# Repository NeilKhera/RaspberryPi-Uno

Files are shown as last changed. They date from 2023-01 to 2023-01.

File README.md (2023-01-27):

## RaspberryPi-Uno
<br/>

### Description
A pin-compatible Arduino Uno clone board for the Raspberry Pi RP2040 microcontroller.

Check out the resources folder for Circuitpython config files, or the Releases section for the compiled firmware .uf2!

### License

Designed by Neil Khera.

Creative Commons Attribution/Share-Alike, all text above must be included in any redistribution. See license.txt for additional details.

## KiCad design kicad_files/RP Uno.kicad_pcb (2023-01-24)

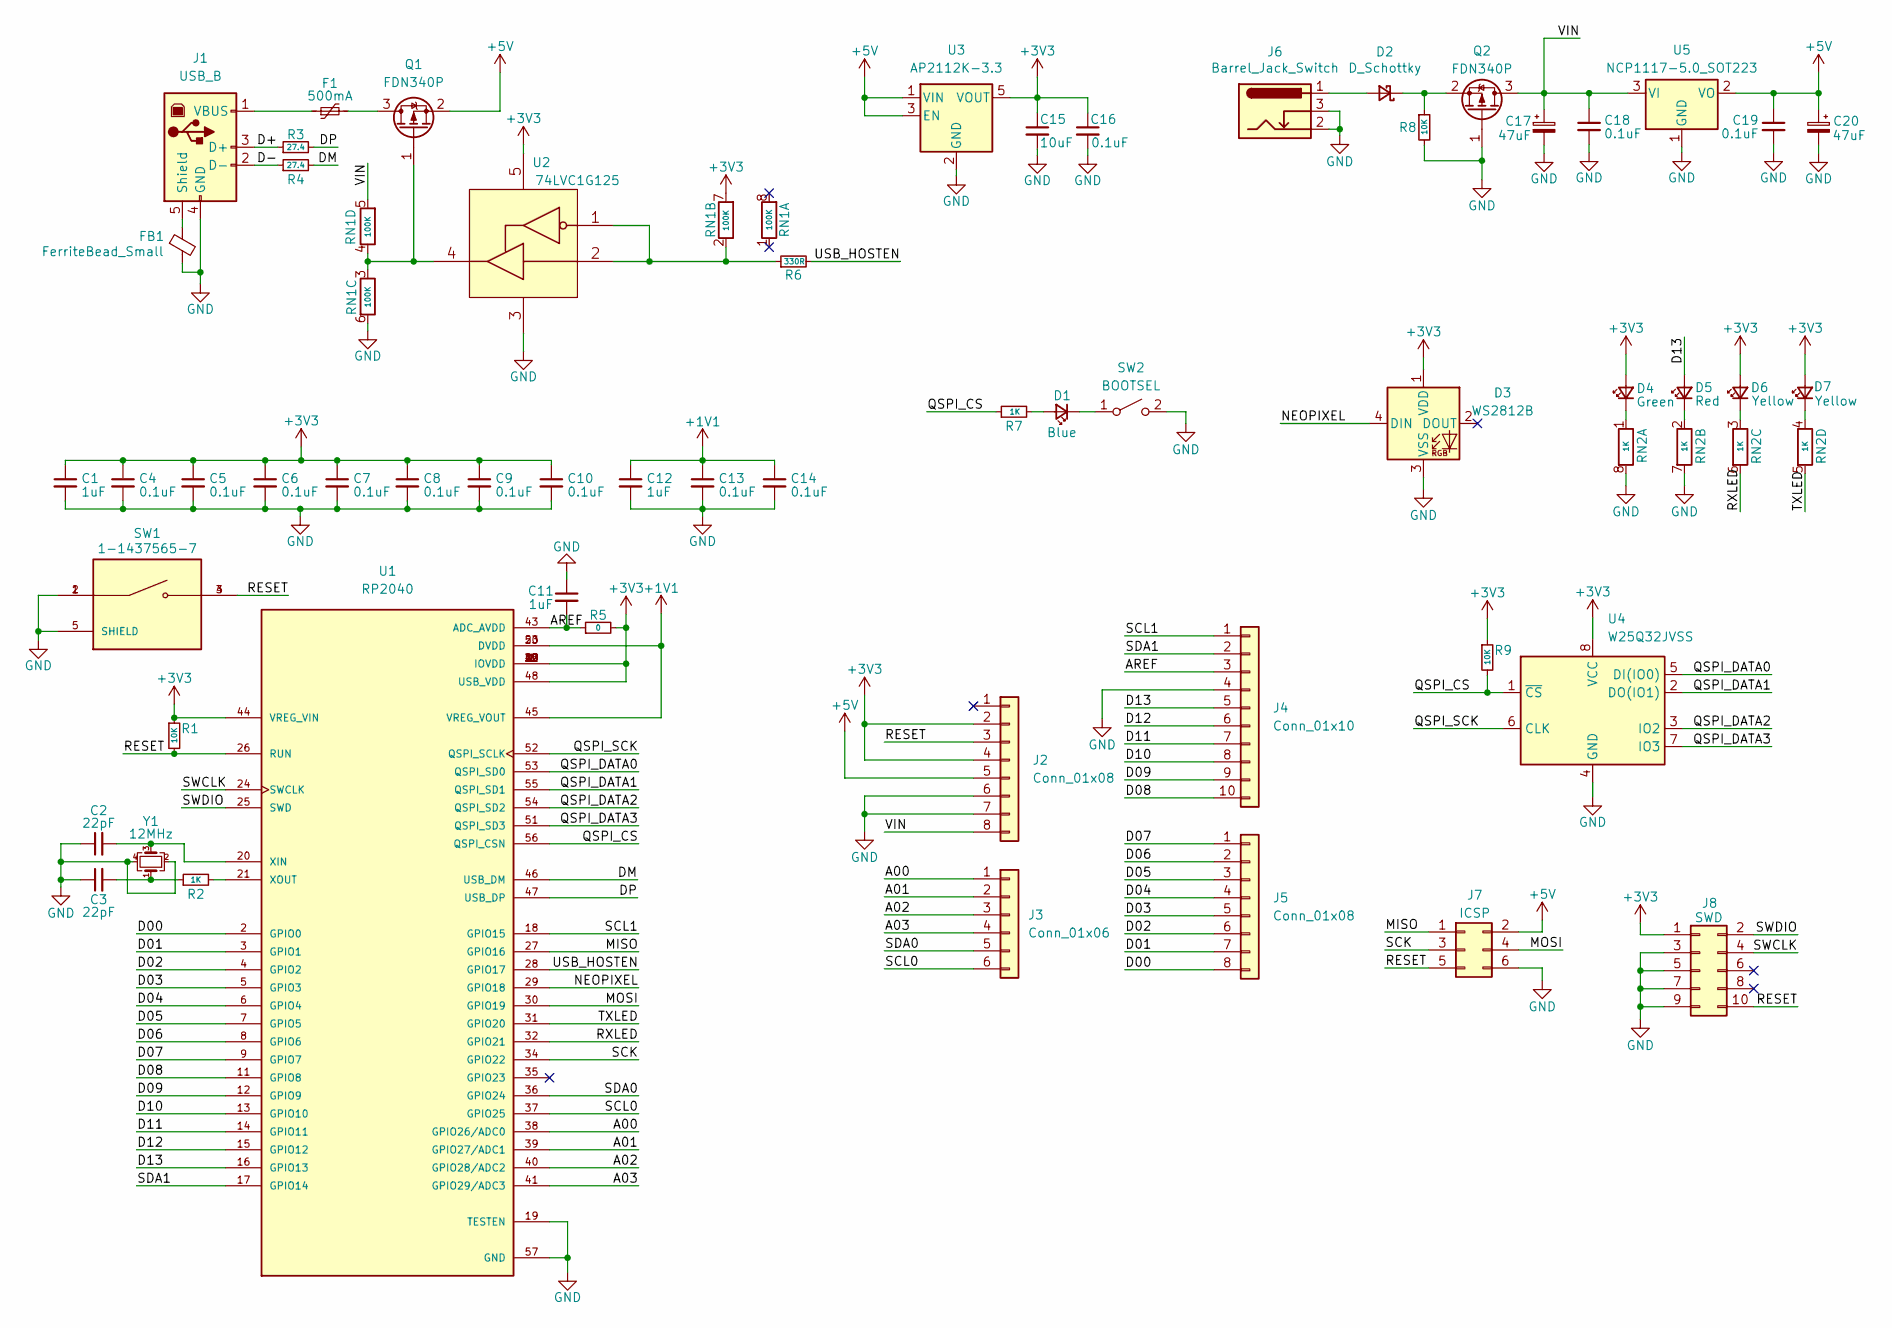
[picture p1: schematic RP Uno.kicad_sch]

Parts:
C1, C11, C12: 1uF; C_0603_1608Metric
C2, C3: 22pF; C_0603_1608Metric
C4, C5, C6, C7, C8, C9, C10, C13, C14, C16, C18, C19: 0.1uF; C_0603_1608Metric
C15: 10uF; C_0603_1608Metric
C17, C20: 47uF; CAPAE680X600N
D1: Blue; LED_0603_1608Metric
D2: D_Schottky; D_SMB
D3: WS2812B; LED_WS2812B_PLCC4_5.0x5.0mm_P3.2mm
D4: Green; LED_0603_1608Metric
D5: Red; LED_0603_1608Metric
D6, D7: Yellow; LED_0603_1608Metric
F1: 500mA; Fuse_1206_3216Metric
FB1: FerriteBead_Small; L_0603_1608Metric
J1: USB_B; USB_B_OST_USB-B1HSxx_Horizontal
J2, J5: Conn_01x08; PinSocket_1x08_P2.54mm_Vertical
J3: Conn_01x06; PinSocket_1x06_P2.54mm_Vertical
J4: Conn_01x10; PinSocket_1x10_P2.54mm_Vertical
J6: Barrel_Jack_Switch; BarrelJack_Horizontal
J7: ICSP; PinHeader_2x03_P2.54mm_Vertical
J8: SWD; 2X05_1.27MM_BOX_POSTS
Q1, Q2: FDN340P; SOT-23
R1, R8, R9: 10K; R_0603_1608Metric
R2, R7: 1K; R_0603_1608Metric
R3, R4: 27.4; R_0603_1608Metric
R5: 0; R_0603_1608Metric
R6: 330R; R_0603_1608Metric
RN1: 100K; R_Array_Concave_4x0603
RN2: 1K; R_Array_Concave_4x0603
SW1: 1-1437565-7; SW_1-1437565-7
SW2: BOOTSEL; SW_SPST_B3U-1000P
U1: RP2040; QFN40P700X700X90-57N; PARTREV 1.6.1
U2: 74LVC1G125; SOT-23-5
U3: AP2112K-3.3; SOT-23-5
U4: W25Q32JVSS; SOIC-8_5.23x5.23mm_P1.27mm
U5: NCP1117-5.0_SOT223; SOT-223-3_TabPin2
Y1: 12MHz; Crystal_SMD_2520-4Pin_2.5x2.0mm

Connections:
+1V1: C12.1, C13.1, C14.1, U1.23 (DVDD), U1.45 (VREG_VOUT), U1.50 (DVDD)
+3V3: C1.1, C4.1, C5.1, C6.1, C7.1, C8.1, C9.1, C10.1, C15.1, C16.1, D3.1 (VDD), D4.2 (A), D6.2 (A), D7.2 (A), J2.2, J2.4, J8.1, R1.1, R5.2, R9.1, RN1.7 (R2.2), U1.1 (IOVDD), U1.10 (IOVDD), U1.22 (IOVDD), U1.33 (IOVDD), U1.42 (IOVDD), U1.44 (VREG_VIN), U1.48 (USB_VDD), U1.49 (IOVDD), U2.5 (VCC), U3.5 (VOUT), U4.8 (VCC)
+5V: C19.1, C20.1, J2.5, J7.2, Q1.2 (S), U3.1 (VIN), U3.3 (EN), U5.2 (VO)
/A00: J3.1, U1.38 (GPIO26/ADC0)
/A01: J3.2, U1.39 (GPIO27/ADC1)
/A02: J3.3, U1.40 (GPIO28/ADC2)
/A03: J3.4, U1.41 (GPIO29/ADC3)
/AREF: C11.2, J4.3, R5.1, U1.43 (ADC_AVDD)
/D00: J5.8, U1.2 (GPIO0)
/D01: J5.7, U1.3 (GPIO1)
/D02: J5.6, U1.4 (GPIO2)
/D03: J5.5, U1.5 (GPIO3)
/D04: J5.4, U1.6 (GPIO4)
/D05: J5.3, U1.7 (GPIO5)
/D06: J5.2, U1.8 (GPIO6)
/D07: J5.1, U1.9 (GPIO7)
/D08: J4.10, U1.11 (GPIO8)
/D09: J4.9, U1.12 (GPIO9)
/D10: J4.8, U1.13 (GPIO10)
/D11: J4.7, U1.14 (GPIO11)
/D12: J4.6, U1.15 (GPIO12)
/D13: D5.2 (A), J4.5, U1.16 (GPIO13)
/D+: J1.3 (D+), R3.1
/D-: J1.2 (D-), R4.1
/DM: R4.2, U1.46 (USB_DM)
/DP: R3.2, U1.47 (USB_DP)
/MISO: J7.1, U1.27 (GPIO16)
/MOSI: J7.4, U1.30 (GPIO19)
/NEOPIXEL: D3.4 (DIN), U1.29 (GPIO18)
/QSPI_CS: R7.1, R9.2, U1.56 (QSPI_CSN), U4.1 (~CS)
/QSPI_DATA0: U1.53 (QSPI_SD0), U4.5 (DI(IO0))
/QSPI_DATA1: U1.55 (QSPI_SD1), U4.2 (DO(IO1))
/QSPI_DATA2: U1.54 (QSPI_SD2), U4.3 (IO2)
/QSPI_DATA3: U1.51 (QSPI_SD3), U4.7 (IO3)
/QSPI_SCK: U1.52 (QSPI_SCLK), U4.6 (CLK)
/RESET: J2.3, J7.5, J8.10, R1.2, SW1.3, SW1.4, U1.26 (RUN)
/RXLED: RN2.6 (R3.2), U1.32 (GPIO21)
/SCK: J7.3, U1.34 (GPIO22)
/SCL0: J3.6, U1.37 (GPIO25)
/SCL1: J4.1, U1.18 (GPIO15)
/SDA0: J3.5, U1.36 (GPIO24)
/SDA1: J4.2, U1.17 (GPIO14)
/SWCLK: J8.4, U1.24 (SWCLK)
/SWDIO: J8.2, U1.25 (SWD)
/TXLED: RN2.5 (R4.2), U1.31 (GPIO20)
/USB_HOSTEN: R6.2, U1.28 (GPIO17)
/VIN: C17.1, C18.1, J2.8, Q2.3 (D), RN1.5 (R4.2), U5.3 (VI)
GND: C1.2, C2.1, C3.1, C4.2, C5.2, C6.2, C7.2, C8.2, C9.2, C10.2, C11.1, C12.2, C13.2, C14.2, C15.2, C16.2, C17.2, C18.2, C19.2, C20.2, D3.3 (VSS), FB1.2, J1.4 (GND), J2.6, J2.7, J4.4, J6.2, J6.3, J7.6, J8.3, J8.5, J8.7, J8.9, Q2.1 (G), R8.2, RN1.6 (R3.2), RN2.7 (R2.2), RN2.8 (R1.2), SW1.1, SW1.2, SW1.5 (SHIELD), SW2.2 (B), U1.19 (TESTEN), U1.57 (GND), U2.3 (GND), U3.2 (GND), U4.4 (GND), U5.1 (GND), Y1.2, Y1.4
unnamed: C2.2, U1.20 (XIN), Y1.3
unnamed: C3.2, R2.1, Y1.1
unnamed: D1.1 (K), SW2.1 (A)
unnamed: D1.2 (A), R7.2
unnamed: D2.1 (K), Q2.2 (S), R8.1
unnamed: D2.2 (A), J6.1
unnamed: D4.1 (K), RN2.1 (R1.1)
unnamed: D5.1 (K), RN2.2 (R2.1)
unnamed: D6.1 (K), RN2.3 (R3.1)
unnamed: D7.1 (K), RN2.4 (R4.1)
unnamed: F1.1, J1.1 (VBUS)
unnamed: F1.2, Q1.3 (D)
unnamed: FB1.1, J1.5 (Shield)
unnamed: Q1.1 (G), RN1.3 (R3.1), RN1.4 (R4.1), U2.4 (Y)
unnamed: R2.2, U1.21 (XOUT)
unnamed: R6.1, RN1.2 (R2.1), U2.1 (OE_N), U2.2 (A)

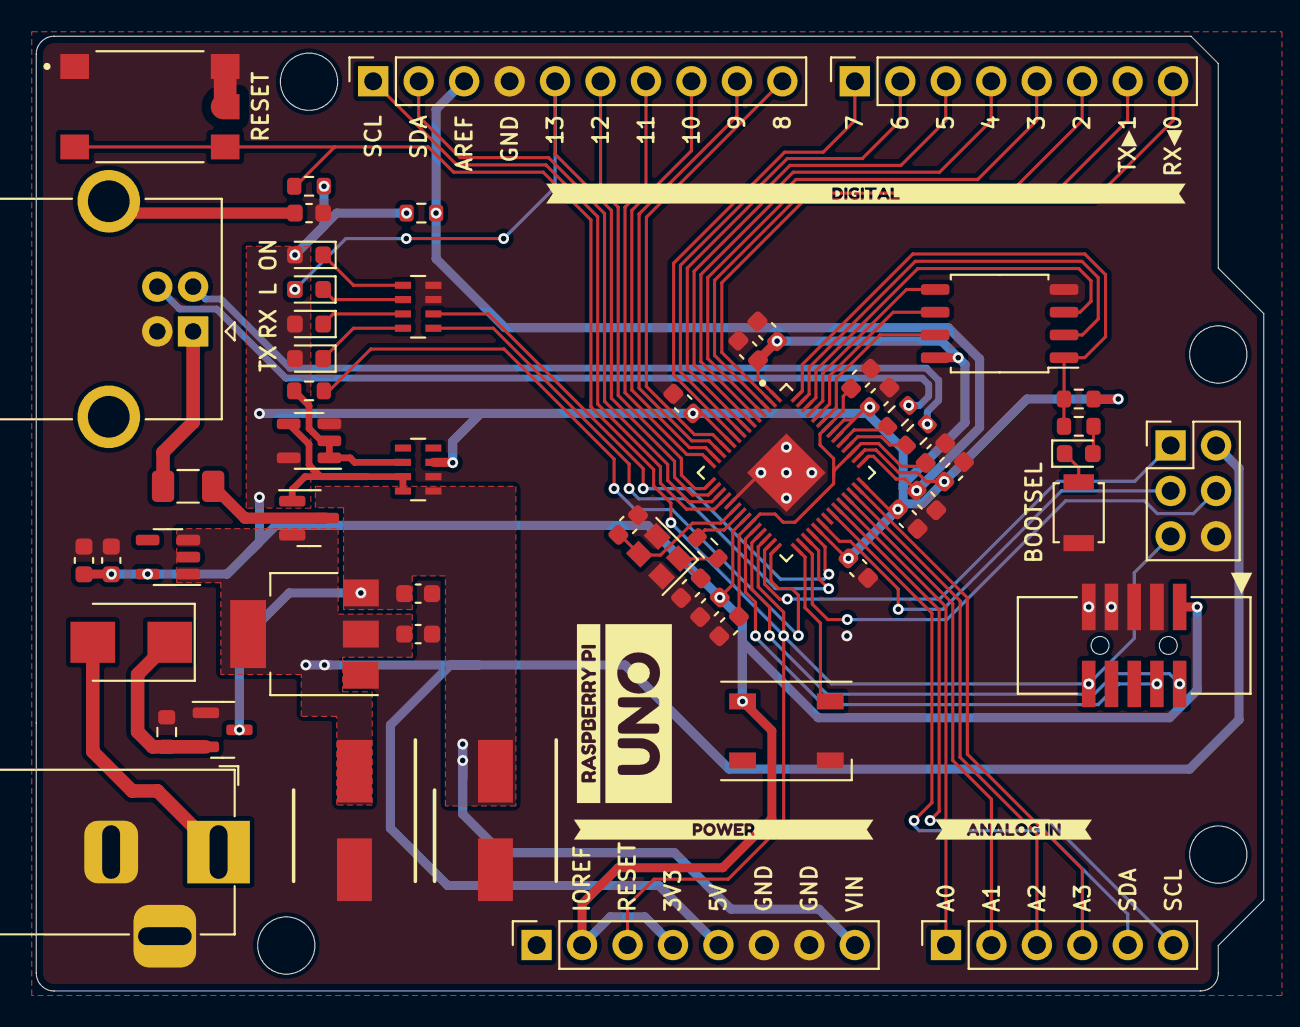
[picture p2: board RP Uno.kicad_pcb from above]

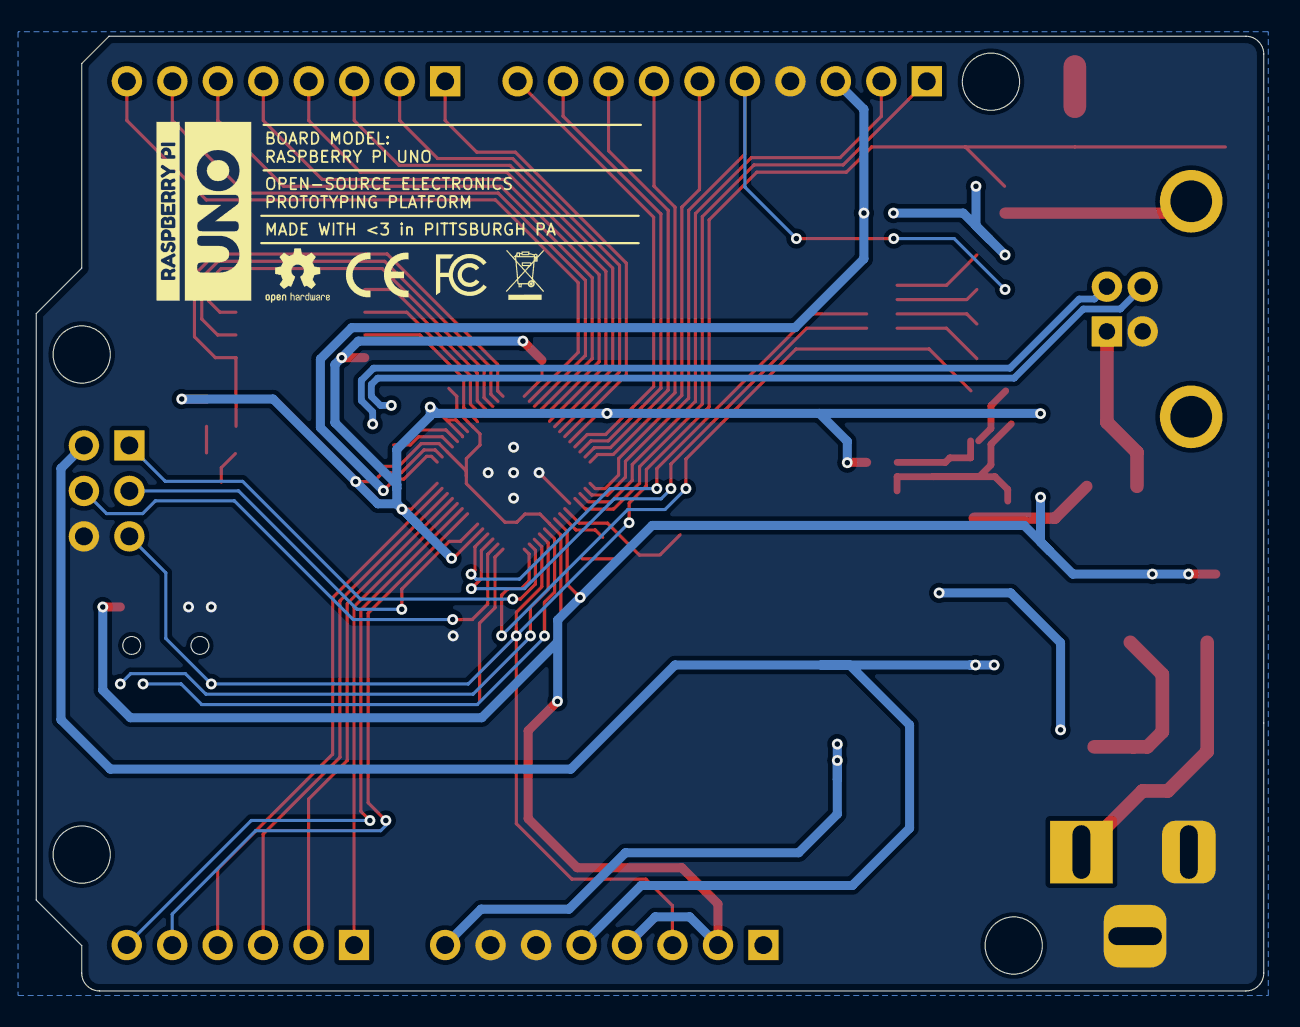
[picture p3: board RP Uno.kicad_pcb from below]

Board: 2 copper layers, 68.6 x 53.3 mm, 69 parts (2 on the bottom side), 64 nets.

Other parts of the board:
@HOLE0, @HOLE1, @HOLE2, @HOLE3: (no value)
kibuzzard-639FD1FE: G***; kibuzzard-639FD1FE
kibuzzard-639FD3EE: G***; kibuzzard-639FD3EE
kibuzzard-639FD17E, kibuzzard-639FD17E#2: G***; kibuzzard-639FD17E
kibuzzard-639FD42A: G***; kibuzzard-639FD42A
kibuzzard-639FD142, kibuzzard-639FD142#2: G***; kibuzzard-639FD142

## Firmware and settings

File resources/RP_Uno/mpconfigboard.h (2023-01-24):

#define MICROPY_HW_BOARD_NAME "Raspberry Pi Uno"
#define MICROPY_HW_MCU_NAME   "rp2040"

#define MICROPY_HW_LED_TX     (&pin_GPIO20)
#define MICROPY_HW_LED_RX     (&pin_GPIO21)

#define MICROPY_HW_LED_STATUS (&pin_GPIO13)
#define MICROPY_HW_NEOPIXEL   (&pin_GPIO18)

#define DEFAULT_I2C_BUS_SCL   (&pin_GPIO15)
#define DEFAULT_I2C_BUS_SDA   (&pin_GPIO14)

#define DEFAULT_SPI_BUS_SCK   (&pin_GPIO22)
#define DEFAULT_SPI_BUS_MOSI  (&pin_GPIO19)
#define DEFAULT_SPI_BUS_MISO  (&pin_GPIO16)

#define DEFAULT_UART_BUS_TX   (&pin_GPIO0)
#define DEFAULT_UART_BUS_RX   (&pin_GPIO1)

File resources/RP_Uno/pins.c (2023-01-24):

#include "shared-bindings/board/__init__.h"

STATIC const mp_rom_map_elem_t board_module_globals_table[] = {
    CIRCUITPYTHON_BOARD_DICT_STANDARD_ITEMS

    { MP_ROM_QSTR(MP_QSTR_TX0), MP_ROM_PTR(&pin_GPIO0) },
    { MP_ROM_QSTR(MP_QSTR_RX0), MP_ROM_PTR(&pin_GPIO1) },

    { MP_ROM_QSTR(MP_QSTR_D0), MP_ROM_PTR(&pin_GPIO0) },
    { MP_ROM_QSTR(MP_QSTR_D1), MP_ROM_PTR(&pin_GPIO1) },
    { MP_ROM_QSTR(MP_QSTR_D2), MP_ROM_PTR(&pin_GPIO2) },
    { MP_ROM_QSTR(MP_QSTR_D3), MP_ROM_PTR(&pin_GPIO3) },
    { MP_ROM_QSTR(MP_QSTR_D4), MP_ROM_PTR(&pin_GPIO4) },
    { MP_ROM_QSTR(MP_QSTR_D5), MP_ROM_PTR(&pin_GPIO5) },
    { MP_ROM_QSTR(MP_QSTR_D6), MP_ROM_PTR(&pin_GPIO6) },
    { MP_ROM_QSTR(MP_QSTR_D7), MP_ROM_PTR(&pin_GPIO7) },
    { MP_ROM_QSTR(MP_QSTR_D8), MP_ROM_PTR(&pin_GPIO8) },
    { MP_ROM_QSTR(MP_QSTR_D9), MP_ROM_PTR(&pin_GPIO9) },
    { MP_ROM_QSTR(MP_QSTR_D10), MP_ROM_PTR(&pin_GPIO10) },
    { MP_ROM_QSTR(MP_QSTR_D11), MP_ROM_PTR(&pin_GPIO11) },
    { MP_ROM_QSTR(MP_QSTR_D12), MP_ROM_PTR(&pin_GPIO12) },
    { MP_ROM_QSTR(MP_QSTR_D13), MP_ROM_PTR(&pin_GPIO13) },

    { MP_ROM_QSTR(MP_QSTR_LED), MP_ROM_PTR(&pin_GPIO13) },


    { MP_ROM_QSTR(MP_QSTR_SDA1), MP_ROM_PTR(&pin_GPIO14) },
    { MP_ROM_QSTR(MP_QSTR_SCL1), MP_ROM_PTR(&pin_GPIO15) },

    { MP_ROM_QSTR(MP_QSTR_MISO), MP_ROM_PTR(&pin_GPIO16) },
    { MP_ROM_QSTR(MP_QSTR_MOSI), MP_ROM_PTR(&pin_GPIO19) },
    { MP_ROM_QSTR(MP_QSTR_SCK), MP_ROM_PTR(&pin_GPIO22) },

    { MP_ROM_QSTR(MP_QSTR_NEOPIXEL), MP_ROM_PTR(&pin_GPIO18) },
    { MP_ROM_QSTR(MP_QSTR_LED_TX), MP_ROM_PTR(&pin_GPIO20) },
    { MP_ROM_QSTR(MP_QSTR_LED_RX), MP_ROM_PTR(&pin_GPIO21) },

    { MP_ROM_QSTR(MP_QSTR_SDA0), MP_ROM_PTR(&pin_GPIO24) },
    { MP_ROM_QSTR(MP_QSTR_SCL0), MP_ROM_PTR(&pin_GPIO25) },


    { MP_ROM_QSTR(MP_QSTR_A0), MP_ROM_PTR(&pin_GPIO26) },
    { MP_ROM_QSTR(MP_QSTR_A1), MP_ROM_PTR(&pin_GPIO27) },
    { MP_ROM_QSTR(MP_QSTR_A2), MP_ROM_PTR(&pin_GPIO28) },
    { MP_ROM_QSTR(MP_QSTR_A3), MP_ROM_PTR(&pin_GPIO29) },


    { MP_ROM_QSTR(MP_QSTR_I2C), MP_ROM_PTR(&board_i2c_obj) },
    { MP_ROM_QSTR(MP_QSTR_SPI), MP_ROM_PTR(&board_spi_obj) },
    { MP_ROM_QSTR(MP_QSTR_UART), MP_ROM_PTR(&board_uart_obj) },
};
MP_DEFINE_CONST_DICT(board_module_globals, board_module_globals_table);

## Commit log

2022-12-19 Pinout changes and silkscreen additions
    [RP Uno.kicad_pcb, RP Uno.kicad_sch]
2023-01-24 Moved stuff around, and added circuitpython firmware config files
    [RP Uno.kicad_pcb, RP Uno.kicad_sch]
